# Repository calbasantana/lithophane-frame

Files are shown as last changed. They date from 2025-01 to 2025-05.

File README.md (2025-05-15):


# Introduction
Over the last couple of years, I've seen a lot of lithophane projects, so I thought it was finally time to make my own. It seems like a significantly better alternative to laser engraving images and some early testing indicated better imaging quality with similar times for engraving/3D printing. I decided to create a lithophane of my amazing cat, Juno, in her halloween costume (she's a batcat).

# Material(s)
Lithophanes require a light source in order to work properly, so the following materials were purchased for this build.

* [4000mAh Soft Light ($19.99)](https://www.amazon.com/gp/product/B09C5XKW64/ref=ppx_yo_dt_b_search_asin_title?ie=UTF8&psc=1)

* [Right Angle USB-C Adapter ($9.99)](https://www.amazon.com/gp/product/B0CNGFZ1JD/ref=ppx_yo_dt_b_search_asin_title?ie=UTF8&th=1)

This project costs approximately $35, maybe $40 including taxes and other stuff.

# Lithophane & Case
This next section covers the 3D-printed case and the 3D-printed lithophane.

## Lithophane
To create the lithophane itself, I went to the following website: https://www.lithophanemaker.com/
 
I then scrolled down to "Flat Lithophane Maker." Here, I uploaded the file of my choosing, which was of my cat Juno in her halloween costume.
### Lithophane Specifications
I used the following settings:

Frame Options: Frame Only \
Crop: Yes \
Lithophane Resolution (mm/pixel): 0.2 \
Width (mm): 125 PLEASE KEEP THIS AT 125! \
Height (mm): 65 PLEASE KEEP THIS AT 65! \
Depth (mm): 7.5 \
Base Height (mm): 7.5 \
Overhang Angle (deg): 60 \
Maximum Thicknesss (mm): 3.0 \
Minimum Thickness (mm): 0.6 \
Stand Thickness (mm): 2 \
Stand Angle (degrees): 75

Once I had dialed these settings in, I clicked on "Create .stl." I extracted the file downloaded and 3D-printed it.
#### Specifications & Material(s)
Below you can find the printer and material used.
##### 3D Printer
 Original Prusa Mini+
##### Material(s)
* [INLAND Marble PLA Filament ($29.99)](https://www.amazon.com/Inland-1-75mm-Marble-Printer-Filament/dp/B08M4733VV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)
##### Software
 PrusaSlicer

##### Settings
  Layer Height: .2mm \
  Infill: 50% \
  Supports: Everywhere \
  Estimated Printing Time: 3 hour and 26 minutes - this will vary depending on your image

## Lithophane Case
For the case, I custom-designed it based on the parts. I wanted to have it on a bed headboard, so I didn't design it to tilt since it would already be about eye level for someone my height. I also wanted to make sure it was easy to keep charged, hence the decision to have the right angle adapter.

#### Specifications & Material(s)
Below you can find the printer and material used.
##### 3D Printer
 Original Prusa Mini+
##### Material(s)
* [INLAND Marble PLA Filament ($29.99)](https://www.amazon.com/Inland-1-75mm-Marble-Printer-Filament/dp/B08M4733VV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)
##### Software
 PrusaSlicer



##### Settings
  Layer Height: .2mm \
  Infill: 25% \
  Supports: Everywhere \
  Estimated Printing Time: 7 hour and 55 minutes

Here you can see the case from the back and how easy it is to access the USB-C port:



# Tips

The case is a little loose on the backside by default; this is so that it is easy to slide the light source in and out, but if you would like a tighter fit, you can add a few pieces of cut hardboard to the left side.

The case might look better with higher contrast, so printing it in black and the lithophane itself in white - which is better than the marble filament used here (in terms of picture quality). It might also look really awesome if the case was printed using a wood filament.

For higher quality images, when slicing your lithophane, I recommend using a lower layer height (I've made a few lithophanes with .05mm layer height and those looked amazing).

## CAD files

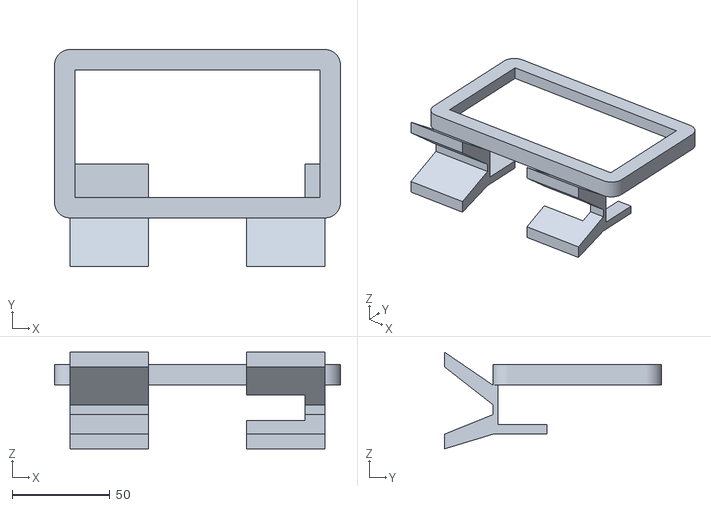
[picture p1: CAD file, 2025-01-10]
Lithophane Frame.stl
146.0 x 110.8 x 49.4
